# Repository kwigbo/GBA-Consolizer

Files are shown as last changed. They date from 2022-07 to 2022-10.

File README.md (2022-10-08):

  
This work is licensed under a [Creative Commons Attribution-ShareAlike 4.0 International License](http://creativecommons.org/licenses/by-sa/4.0/).

Complete Demo

# Support
[https://www.buymeacoffee.com/kwigbo](https://www.buymeacoffee.com/kwigbo)

# GBA-Consolizer
**GBA Consolizer 3D Printable Case. Build your own Gameboy Advance console! This was designed to have multiple customization points and works with both Gamebox Systems and Woozle consolizer kit. This can also be adapted to any new consolizer kits that may come out in the future. Uses an AGB Gameboy Advance main board.**

# Steps
* **[STEP 1 - Setup](Steps/Step1.md)**
* **[STEP 2 - GBA Prep](Steps/Step2.md)**
* **[STEP 3 - Motherboard Mount](Steps/Step3.md)**
* **[STEP 4 - Consolizer Mount](Steps/Step4.md)**
* **[STEP 5 - Gamebox GBA HD Adapter](Steps/Step5.md)**
* **[STEP 6 - Support Bar](Steps/Step6.md)**
* **[STEP 7 - Frame Assembly (Gamebox)](Steps/Step7.md)**
* **[STEP 7 - Frame Assembly (Woozle)](Steps/Step7b.md)**
* **[STEP 8 - Catridge Tray](Steps/Step8.md)**
* **[STEP 9 - Face Plate](Steps/Step9.md)**
* **[STEP 10 - Rear Plate](Steps/Step10.md)**
* **[STEP 11 - Consolizer Shell](Steps/Step11.md)**
* **[STEP 12 - Lid](Steps/Step12.md)**
* **[STEP 13 - Woozle Gameboy Switch](Steps/Step13.md)**
* **[STEP 14 - Amiibo Holder](Steps/Step14.md)**

Complete Demo
Complete Demo
Complete Demo

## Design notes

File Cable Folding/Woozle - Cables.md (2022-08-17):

# Woozle Cable Folding

**[< -- GBA Prep](../Steps/Step2.md)**

CPU Cable
Display Cable
Complete

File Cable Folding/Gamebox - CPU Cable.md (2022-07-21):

# Gamebox CPU Cable Folding

**[< -- GBA Prep](../Steps/Step2.md)**

Step 1
Step 2
Step 3
Step 4
Complete

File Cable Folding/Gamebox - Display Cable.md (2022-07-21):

# Gamebox Display Cable Folding

**[< -- GBA Prep](../Steps/Step2.md)**

Step 1
Step 2
Step 3
Step 4
Complete

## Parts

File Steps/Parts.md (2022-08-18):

# Parts 

* **Flat Head Machine Screws -> [Amazon](https://a.co/d/2D0doJf)**
* **Brass Embedded Nuts -> [Amazon](https://a.co/d/0SNjTzL)**
* **Rubber Feet -> [Amazon](https://a.co/d/iRyxWAl)**

## Common Parts

* **GBA Frame: 4 - M2x8 Brass Inserts**
* **GBA Front Connection ( Top of GBA ): 2 - M2x10 Screws** 
* **GBA Back Connection: 2 - M2x6 Screws** 
* **Main Shell Connection: 2 - M3x8**
* **4 - 10mmx2mm Rubber Feet**

## GBA Consolizer Mount: 

* **4 - M2x4 Brass Inserts** 
* **2 - M3x8 Brass Inserts**
* **4 - M2x8 Screws**

## Gamebox Parts

* **LED Button ( Gamebox ) -> [Amazon](https://a.co/d/2u8QrSU)**
* **GBHD Screws: 4 - M3x6 Screws**

## Frame Adapter: 

* **4 - M3x8 Brass Inserts**
* **4 - M2x8 Screws**

## Rear Faceplate Connection: 

* **2 - M3x8 Screws** 
* **2 - M2x6 Brass Inserts**
* **2 - M2x8 Screws**

## Woozle Parts

* **Switches -> [Amazon](https://a.co/d/1mCzNco)**
* **LEDs -> [Amazon](https://a.co/d/bPgX2ja)**
* **Switch Board -> [Gerber](../Woozle%20Switch%20Gerber)**

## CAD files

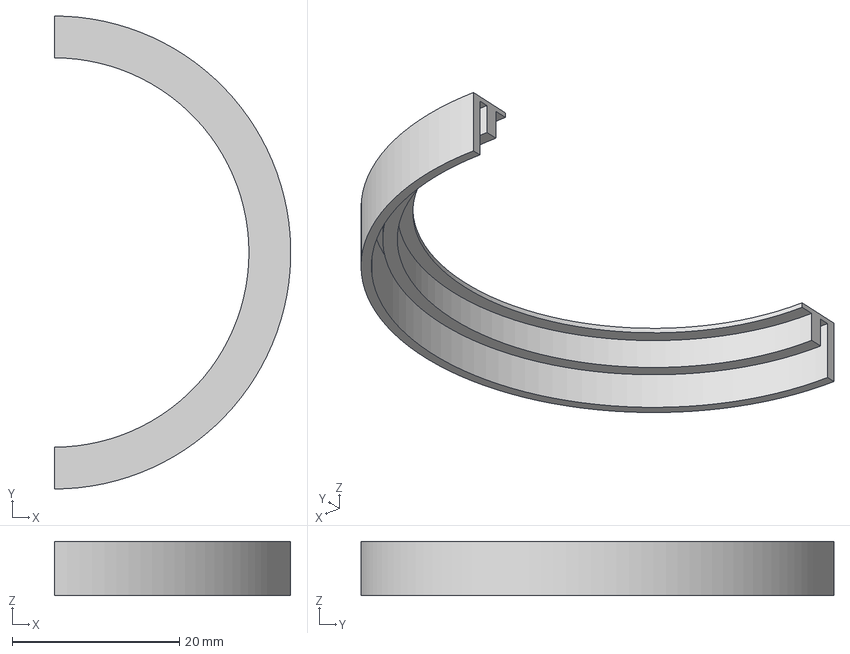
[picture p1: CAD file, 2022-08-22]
Models/Amiibo_Top_Clip_Full.3mf
28.2 x 56.5 x 6.50 mm

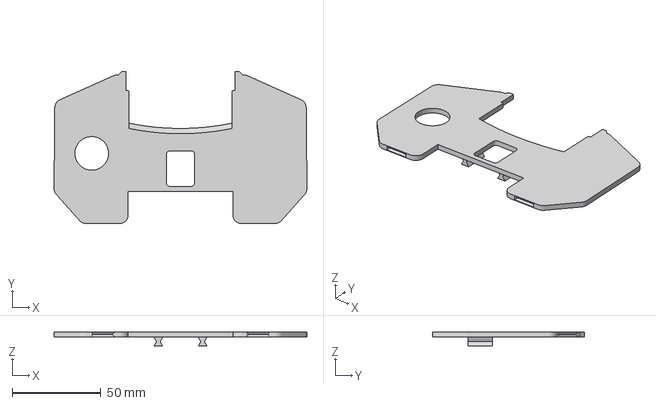
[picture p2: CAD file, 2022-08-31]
Models/Lid_Type_5.3mf
142.8 x 85.9 x 8.00 mm

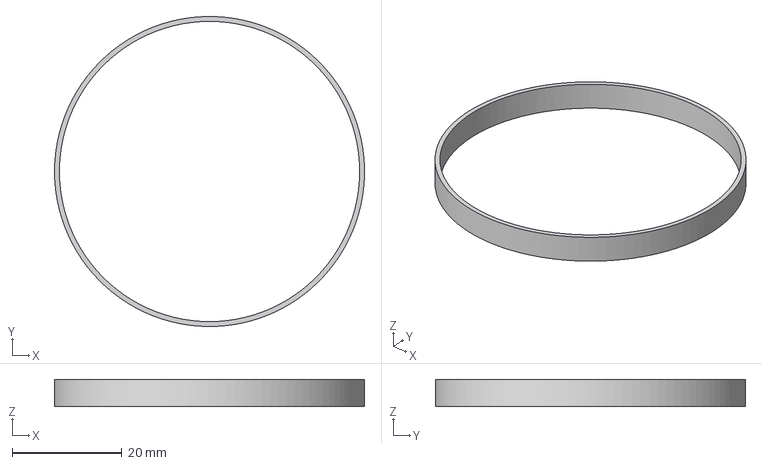
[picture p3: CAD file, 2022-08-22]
Models/Amiibo_Decorative_Ring.3mf
56.5 x 56.5 x 5.00 mm

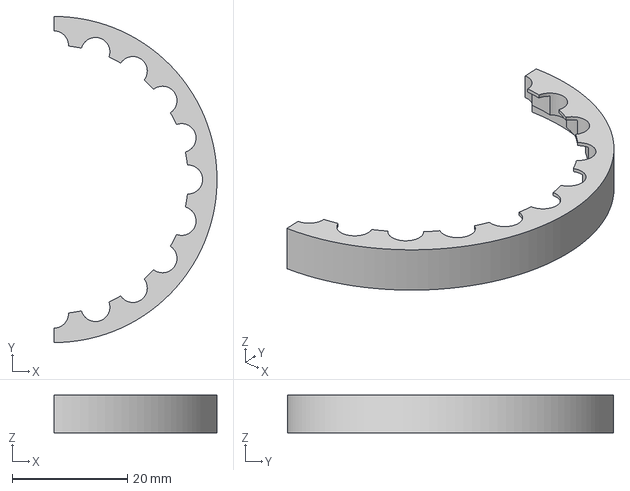
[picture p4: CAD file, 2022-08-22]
Models/Amiibo_Top_Clip_Notched.3mf
28.2 x 56.5 x 6.50 mm

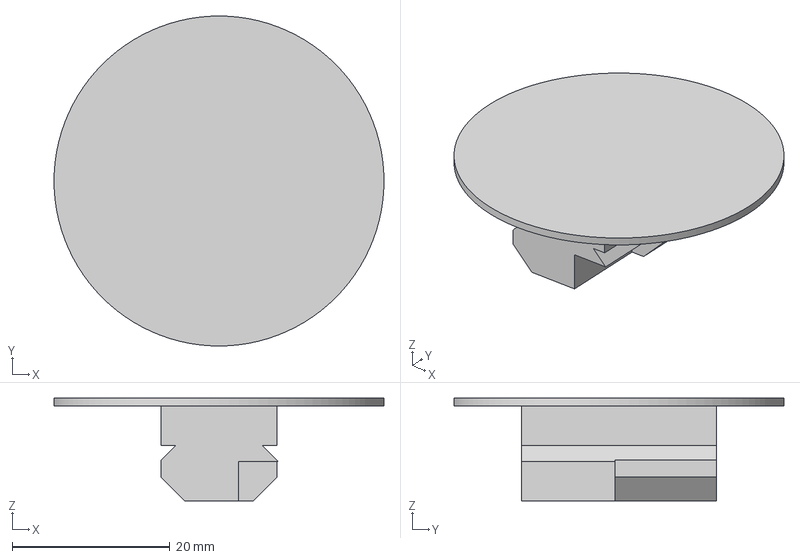
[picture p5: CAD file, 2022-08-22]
Models/Amiibo_Holder_Post_Capacitor_Clearance.3mf
41.8 x 41.8 x 13.0 mm

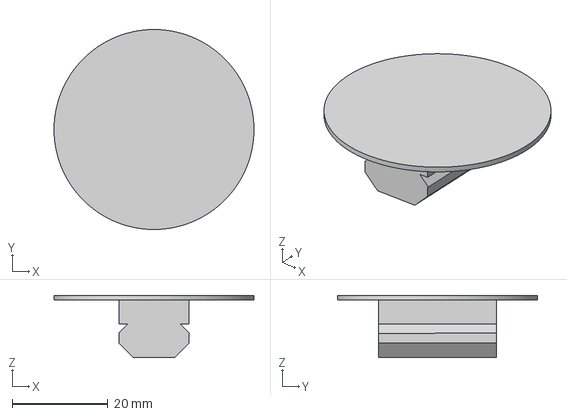
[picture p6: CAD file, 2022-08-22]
Models/Amiibo_Holder_Post.3mf
41.8 x 41.8 x 13.0 mm

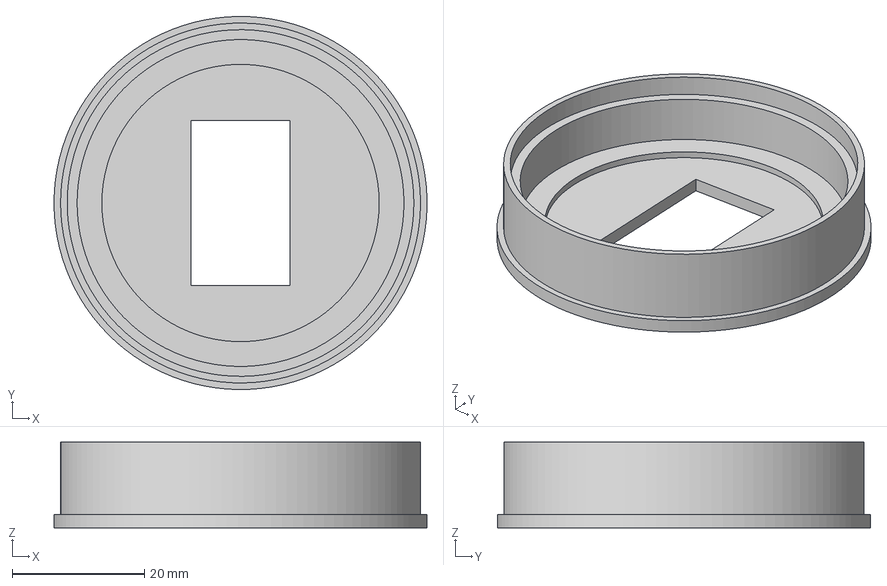
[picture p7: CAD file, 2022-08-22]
Models/Amiibo_Holder_Tray.3mf
56.5 x 56.5 x 13.0 mm

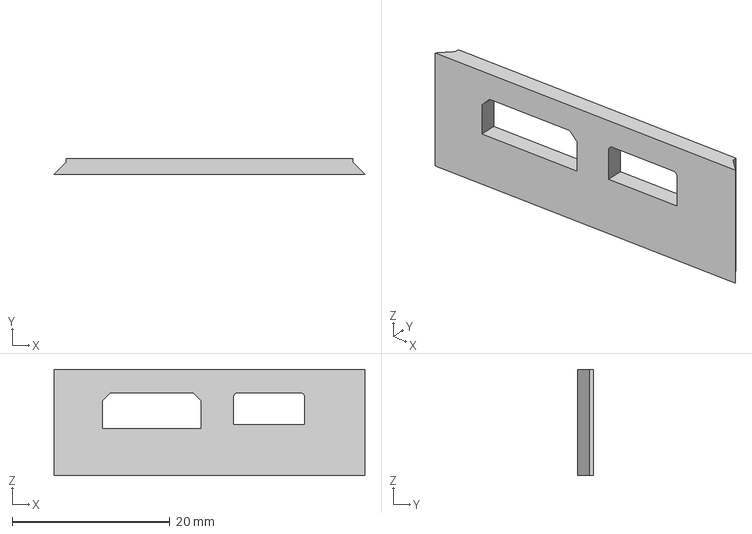
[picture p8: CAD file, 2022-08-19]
Models/Rear_Portplate_Face_Woozle.3mf
39.4 x 2.00 x 13.5 mm

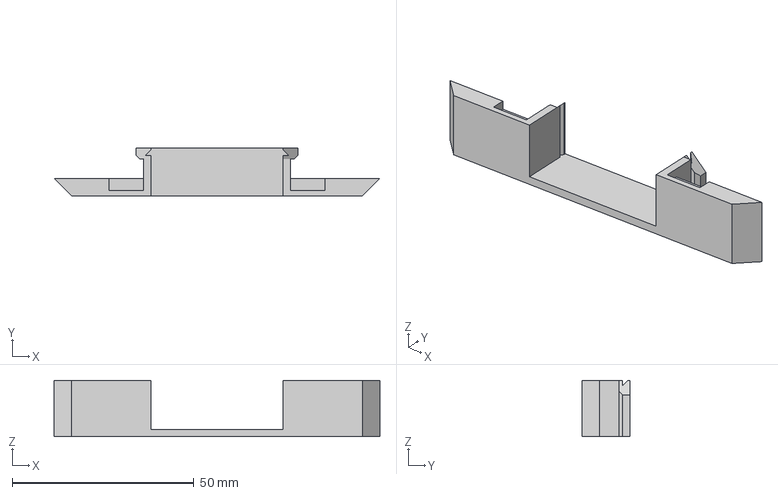
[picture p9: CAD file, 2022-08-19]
Models/Rear_Portplate_Woozle.3mf
89.7 x 13.2 x 15.5 mm

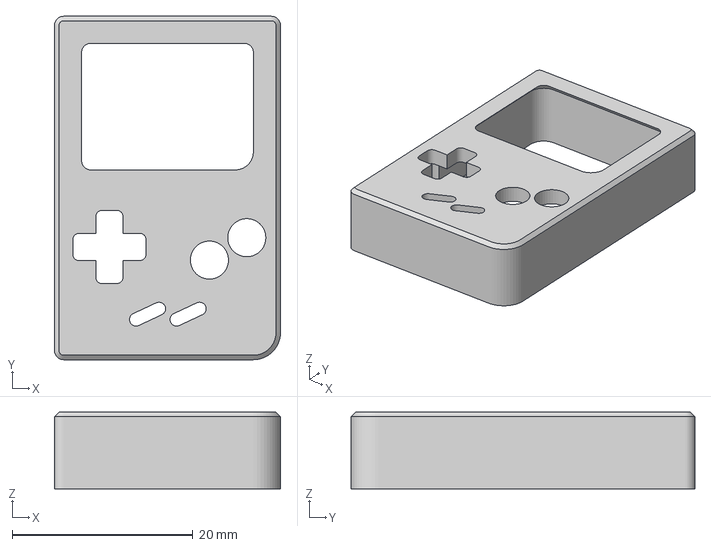
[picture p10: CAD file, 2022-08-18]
Models/Woozle_Gameboy_Switch_Body.3mf
25.0 x 38.0 x 8.50 mm

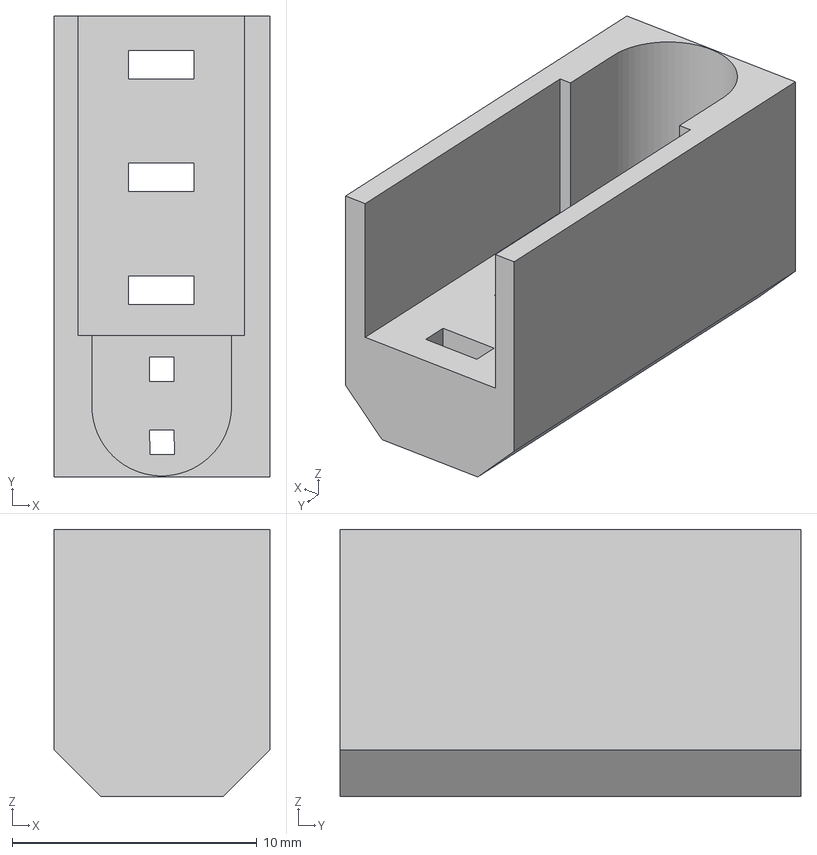
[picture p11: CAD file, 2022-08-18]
Models/Woozle_Switch_Component_Holder.3mf
8.80 x 18.8 x 10.9 mm

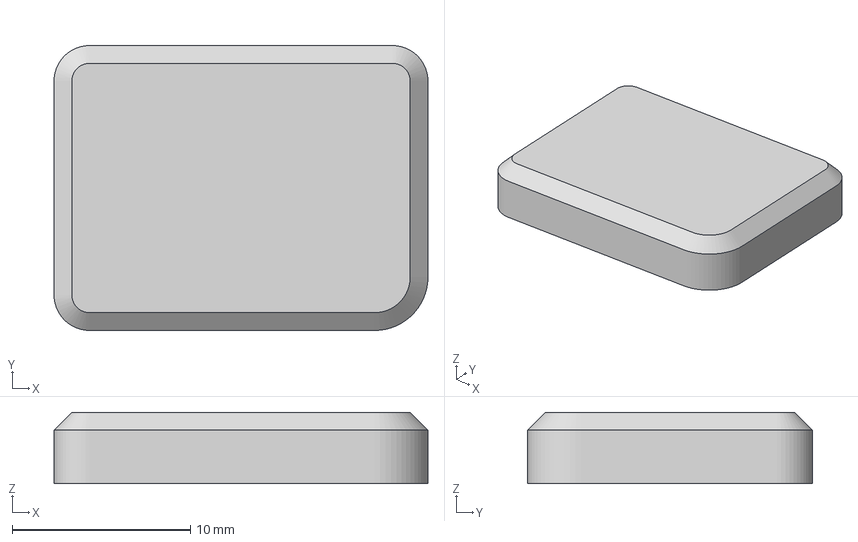
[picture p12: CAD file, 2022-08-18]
Models/Woozle_Gameboy_Switch_Screen.3mf
21.0 x 16.0 x 4.00 mm

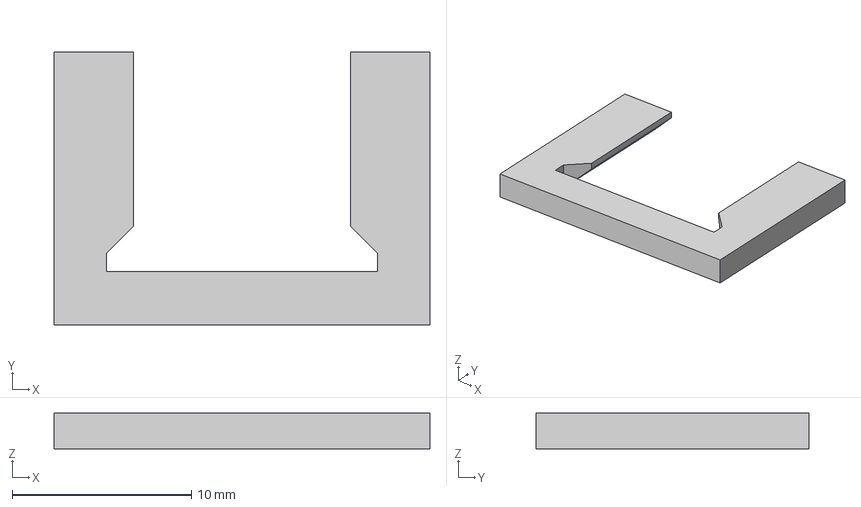
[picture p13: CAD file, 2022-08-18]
Models/Feature_Hold_Down_Pin.3mf
21.0 x 15.3 x 2.00 mm

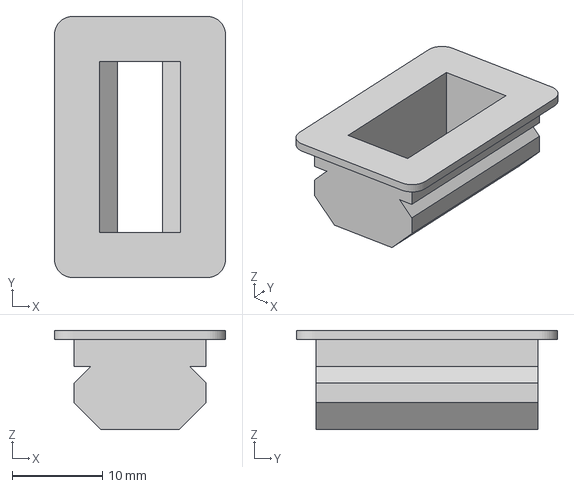
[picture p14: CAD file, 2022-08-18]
Models/Woozle_Switch_Post.3mf
19.0 x 29.0 x 11.0 mm

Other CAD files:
Models/Woozle_Gameboy_Switch_Buttons.3mf
Models/Rear_Plate_Bottom_Woozle.3mf
Models/Face_Plate_Woozle.3mf
Models/Support_Bar_Woozle.3mf
Models/Board_Adapter_Left_Gamebox.3mf
Models/Board_Adapter_Left_Inserts_Gamebox.3mf
Models/Board_Adapter_Right_Gamebox.3mf
Models/Board_Adapter_Right_Inserts_Gamebox.3mf
Models/Calibration_Bottom_Block_Inserts.3mf
Models/Calibration_Bottom_Block_No_Inserts.3mf
Models/Calibration_Top_Block.3mf
Models/Cartridge_Tray_Base_32.3mf
Models/Cartridge_Tray_Base_40.3mf
Models/Cartridge_Tray_Mount_32.3mf
Models/Cartridge_Tray_Mount_40.3mf
Models/Consolizer_Mount_Left.3mf
Models/Consolizer_Mount_Left_Inserts.3mf
Models/Consolizer_Mount_Right.3mf
Models/Consolizer_Mount_Right_Inserts.3mf
Models/Consolizer_Shell.3mf
Models/Eject_Holder.3mf
Models/Eject_Holder_Inserts.3mf
Models/Eject_Holder_Plate.3mf
Models/Eject_Switch.3mf
Models/Face_Plate_Button_Cap_Gamebox.3mf
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

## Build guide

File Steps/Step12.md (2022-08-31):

# STEP 12 - Lid

**[< -- Go Back](../README.md)**

**Print a Lid variation, Eject Switch, Eject Holder Plate and an Eject Holder. The Eject Holder is the only part with an inserts or no inserts version.**

## Parts

* **2 - M2x6 Screws**
* **2 - M2x6 Brass Inserts**

## Files

* **Lids**
	* [Lid Type 1](../Models/Lid_Type_1.3mf)
	* [Lid Type 2](../Models/Lid_Type_2.3mf)
	* [Lid Type 3](../Models/Lid_Type_3.3mf)
	* [Lid Type 4](../Models/Lid_Type_4.3mf)
	* [Lid Type 5](../Models/Lid_Type_5.3mf)
* [Eject Switch](../Models/Eject_Switch.3mf)
* [Eject Holder Plate](../Models/Eject_Holder_Plate.3mf)
* **Eject Holder**
	* [Eject Holder - Inserts](../Models/Eject_Holder_Inserts.3mf)
	* [Eject Holder - No Inserts](../Models/Eject_Holder.3mf)

## Printing Details

* No supports
* 0.2mm layer height

## Lid Types

* **Type 1:** No Holes for embelishment adapters.
* **Type 2:** One embelisment hole ( Left )
* **Type 3:** Two embelisment holes ( Left and Right )
* **Type 4:** One embelisment hole ( Left ) and one circular hole right.
* **Type 5:** One circular hole right.

**Choose a type and print. Type 1 is the minimum needed to cover the top and will be outlined here. All others install the same, they just have options for decorations which will be outlined in the next step.**

## Step 1

**With the Lid upside-down, insert the eject switch as shown below.**

Step 1

## Step 2

**Slide the Eject Holder over the bowtie posts on the Lid. This should slide on loosley and will be secured in a later step.**

Step 2

## Step 3

**Snap the Lid into place. Some pressure is needed and it will click into place.**

Step 3

## Step 4

**Slide the Eject Holder Plate into the slots on the back and secure with two M2x6 Screws.**

Step 4
Step 5

## Complete!!

Step 6

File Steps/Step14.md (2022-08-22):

# STEP 14 - Amiibo Holder

**[< -- Go Back](../README.md)**

**This is not guaranteed to fit all Amiibo. The concept is pretty simple though and Amiibo specific versions are not to difficult to create.**

## Files

* [Amiibo Holder Post - Capacitor](../Models/Amiibo_Holder_Post_Capacitor_Clearance.3mf)
	* This version is for stock capacitor clearance on the left of the console
* [Amiibo Holder Post - Normal](../Models/Amiibo_Holder_Post.3mf)
	* This version does not have the cutout to clear the tall capacitor that is stock on a GBA.
* [Holddown Pin](../Models/Feature_Hold_Down_Pin.3mf)
* [Top Clip Full](../Models/Amiibo_Top_Clip_Full.3mf)
* [Top Clip Notched](../Models/Amiibo_Top_Clip_Notched.3mf)
* [Holder Tray](../Models/Amiibo_Holder_Tray.3mf)
* [Decorative Ring](../Models/Amiibo_Decorative_Ring.3mf)

## Parts Needed
* 1x Holder Post Variant
* 2x Holddown Pins
* 2x Top Clips
* 1x Decorative Ring
* 1x Holder Tray

**Push the Holder Post into the Holder Tray and install in the lid of the consolizer with the two Holddown Pins. Slide the Decorative Ring over the Holder Tray and place an Amiibox in the tray. Use the Holddown Pins to secure the Amiibo in place. The Notched variety helps when there are small pieces of the Amiibo that go beyond the bounds of the tray.**

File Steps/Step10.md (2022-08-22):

# STEP 10 - Rear Plate

**[< -- Go Back](../README.md)**

**Print all pieces flat side down. Note: The Rear Portplate has insets on the back to indicate front and back.**

## Parts

* **2 - M2x8 Screws**

## Files

* **Common Parts**
	* [Rear Plate Top](../Models/Rear_Plate_Top.3mf)
	* [Screw Cover Plate](../Models/Screw_Cover_Plate.3mf)
* **Gamebox Systems**
	* [Rear Portplate](../Models/Rear_Portplate_Gamebox.3mf)
	* [Rear Plate Bottom](../Models/Rear_Plate_Bottom_Gamebox.3mf)
* **Woozle**
	* [Rear Portplate](../Models/Rear_Portplate_Woozle.3mf)
	* [Rear Plate Bottom](../Models/Rear_Plate_Bottom_Woozle.3mf)
	* [Rear Portplate Face](../Models/Rear_Portplate_Face_Woozle.3mf)

## Printing Details

* No supports
* 0.2mm layer height

## Assembly - Step 1

**Slide the Rear Portplate into the Rear Plate Bottom with the indents on the same side as the screw holes of the Rear Plate Bottom (See images below).**

**Note: The Woozle version of the Rear Portplate has an extra piece that has to be slid into place in this step as well. The wide side of the plate goes towards the back of the console.**

Step 1
Step 2

## Assembly - Step 2

**Slide the assembled Rear Plate Bottom onto the Support Bar. Make sure the holes line up. You may have to wiggle the Portplate in order to slide it into position.**

Step 3

## Assembly - Step 3

**Slide the Rear Plate Top into position lined up with the screw holes and attach with the 2 - M2x8 Screws. The screws go through both plates into the Support Bar.**

Step 4

## Assembly - Step 4

**Place the Screw Cover Plate over the screws. This sits in place and will be secured with the lid.**

Step 5

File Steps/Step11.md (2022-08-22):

# STEP 11 - Consolizer Shell

**[< -- Go Back](../README.md)**

**This is a multi-part model but is printed as one piece. The floor is a seperate piece so it can be printed as an infill pattern with zero top layers and zero bottom layers. ( Might be Prusa Slicer only? )**

## Parts

* **2 - M3x8**
* **4 - 10mmx2mm Rubber Feet**

## Files

* [Consolizer Shell](../Models/Consolizer_Shell.3mf)

## Printing Details

* Time: ~5hrs
* No supports
* 0.2mm layer height

**Slide the assembled console frame into the Consolizer Shell. There are alignment posts to help put it in the right position. It should slip right in. Connect the frame to the shell with the two M3x8 SCrews from the bottom ( See images below ). Also, stick the four rubber feet on if desired.**

Step 1
Step 2

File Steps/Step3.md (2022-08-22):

# STEP 3 - Motherboard Mount

**[< -- Go Back](../README.md)**

**Choose a version to print and install the brass inserts/pre-tap the holes.**

## Files

* **Motherboard Mount**
	* [Motherboard Mount Inserts](../Models/Motherboard_Mount_Inserts.3mf)
	* [Motherboard Mount No Inserts](../Models/Motherboard_Mount.3mf)

## Printing Details

**Print the model flat side down. There is a difference as one side has to clear the components on the GBA board.**

* No supports
* 0.2mm layer height

## Brass Inserts

**Four M2x8 brass inserts are need for this part if printing the inserts version.**

**IMPORTANT!: Make sure all matting surfaces (top and bottom) are flush when installing the inserts. Any globs of plastic will affect the final fitment. A razor blade can help especially right after install before the plastic has cooled.Refer the the image below when installing.**

Motherboard Mount

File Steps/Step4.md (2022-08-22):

# STEP 4 - Consolizer Mount

**[< -- Go Back](../README.md)**

**Choose a version to print and install the brass inserts/pre-tap the holes.**

## Files

* **Consolizer Mount**
	* [Consolizer Mount Right Inserts](../Models/Consolizer_Mount_Right_Inserts.3mf)
	* [Consolizer Mount Left Inserts](../Models/Consolizer_Mount_Left_Inserts.3mf)
	* [Consolizer Mount Right No Inserts](../Models/Consolizer_Mount_Right.3mf)
	* [Consolizer Mount Left No Inserts](../Models/Consolizer_Mount_Left.3mf)

## Printing Details

**Print the model flat side down.**

* No supports
* 0.2mm layer height

## Brass Inserts

* **4 - M2x4 Brass Inserts** 
* **2 - M3x8 Brass Inserts**

**IMPORTANT!: Make sure all matting surfaces (top and bottom) are flush when installing the inserts. Any globs of plastic will affect the final fitment. A razor blade can help especially right after install before the plastic has cooled. Refer the the image below when installing. Two post will remain empty and are a passthrough hole for screws in another step.**

Consolizer Mount

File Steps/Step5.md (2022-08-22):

# STEP 5 - Gamebox GBA HD Adapter

**[< -- Go Back](../README.md)**

**Choose a version to print and install the brass inserts/pre-tap the holes.**

## Files

* **Consolizer Mount**
	* [Board Adapter Right Inserts](../Models/Board_Adapter_Right_Inserts_Gamebox.3mf)
	* [Board Adapter Left Inserts](../Models/Board_Adapter_Left_Inserts_Gamebox.3mf)
	* [Board Adapter Right No Inserts](../Models/Board_Adapter_Right_Gamebox.3mf)
	* [Board Adapter Left No Inserts](../Models/Board_Adapter_Left_Gamebox.3mf)

## Printing Details

**Print the model flat side down.**

* No supports
* 0.2mm layer height

## Brass Inserts

* **4 - M3x8 Brass Inserts**

**IMPORTANT!: Make sure all matting surfaces (top and bottom) are flush when installing the inserts. Any globs of plastic will affect the final fitment. A razor blade can help especially right after install before the plastic has cooled. Refer the the image below when installing.**

Board Adapter

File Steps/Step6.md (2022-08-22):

# STEP 6 - Support Bar

**[< -- Go Back](../README.md)**

**Choose a version to print and install the brass inserts/pre-tap the holes.**

## Files

* **Support Bar (Gamebox)**
	* [Support Bar Inserts](../Models/Support_Bar_Inserts_Gamebox.3mf)
	* [Support Bar No Inserts](../Models/Support_Bar_Gamebox.3mf)

* **Support Bar (Woozle)**
	* [Support Bar Inserts](../Models/Support_Bar_Inserts_Woozle.3mf)
	* [Support Bar No Inserts](../Models/Support_Bar_Woozle.3mf)

## Printing Details

**Print the model flat side down.**

* No supports
* 0.2mm layer height

## Brass Inserts

* **2 - M2x6 Brass Inserts - Gamebox**
* **2 - M2x4 Brass Inserts - Woozle**

**Inserts for the woozle bar are slightly shorter.**

**IMPORTANT!: Make sure all matting surfaces (top and bottom) are flush when installing the inserts. Any globs of plastic will affect the final fitment. A razor blade can help especially right after install before the plastic has cooled.Refer the the image below when installing.**

Support Bar

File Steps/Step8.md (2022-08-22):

# STEP 8 - Cartride Tray

**[< -- Go Back](../README.md)**

**Print the Cartridge Tray Base face down. The tray works for both 32 and 40 pin models. Print the Cartridge Tray Mount flat side down. There are two variation of this based on 32 or 40 pin GBA. A slight dab of super glue attaches the Cartridge Tray Base to the Cartridge Tray Mount**

**Place the Cartrige Tray Assembly in position as shown below. Be carful of the components on the board. It should slip into place under the cartridge port.**

**No Screws needed yet as the screws from the faceplate will pass through this part to hold it in place.**

## Files

* **32 Pin**
	* [Cartridge Tray Base ( 32 pin )](../Models/Cartridge_Tray_Base_32.3mf)
	* [Cartridge Tray Mount ( 32 pin )](../Models/Cartridge_Tray_Mount_32.3mf)
* **40 Pin**
	* [Cartridge Tray Base ( 40 pin )](../Models/Cartridge_Tray_Base_40.3mf)
	* [Cartridge Tray Mount ( 40 pin )](../Models/Cartridge_Tray_Mount_40.3mf)

## Printing Details

* No supports
* 0.2mm layer height

Cartridge Tray

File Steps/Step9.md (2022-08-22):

# STEP 9 - Face Plate

**[< -- Go Back](../README.md)**

**Print the Face Plate face down. Print the button with the narrow side down.**

**Place the button in the Face Plate and gently rest the tabs over the Catridge Tray Holes. Flip it over and gently pull the bottom of the Face Plate over the SNES port. It should fit right in with possibly a slight click into place (See Image Face Plate A and B).**

**Check that the button clicks easy and does not stick. Check that the Face Plate sits flush against the SNES port.**

**Use two M2x10 screws through both the Face Plate and the Cartridge Tray to secure both (See Image Face Plate C).**

## Parts

* 2 - M2x10 Screws

## Files

* **Gamebox Systems**
	* [Faceplate](../Models/Face_Plate_Gamebox.3mf)
	* [Button](../Models/Face_Plate_Button_Cap_Gamebox.3mf)
* **Woozle**
	* [Faceplate](../Models/Face_Plate_Woozle.3mf)

## Printing Details

* No supports
* 0.2mm layer height

Face Plate A
Face Plate B
Face Plate C

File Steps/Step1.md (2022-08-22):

# STEP 1 - Setup

**[< -- Go Back](../README.md)**

**Print the test pieces and gather parts.**

[Parts List](Parts.md)

## Files

* [Top Block](../Models/Calibration_Top_Block.3mf)
* **Print the bottom based on whether you will use inserts or not.**
	* [Bottom Block Inserts](../Models/Calibration_Bottom_Block_Inserts.3mf)
	* [Bottom Block No Inserts](../Models/Calibration_Bottom_Block_No_Inserts.3mf)

## Printing Details

* No supports
* 0.2mm layer height

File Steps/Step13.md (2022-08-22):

# STEP 13 - Woozle Gameboy Switch

**[< -- Go Back](../README.md)**

**You will need one switch and one LED along with the PCB and printed parts to complete the switch.**

* **Switch Board -> [Gerber](../Woozle%20Switch%20Gerber)**
* **Switches -> [Amazon](https://a.co/d/1mCzNco)**
* **LEDs -> [Amazon](https://a.co/d/bPgX2ja)**

## Files

* **Component Post**
	* [Component Holder](../Models/Woozle_Switch_Component_Holder.3mf)
	* [Switch Post](../Models/Woozle_Switch_Post.3mf)
	* [Holddown Pin x 2](../Models/Feature_Hold_Down_Pin.3mf)
* **Gameboy Parts**
	* [Gameboy Body](../Models/Woozle_Gameboy_Switch_Body.3mf)
	* [Gameboy Screen](../Models/Woozle_Gameboy_Switch_Screen.3mf)
	* [Gameboy Buttons](../Models/Woozle_Gameboy_Switch_Buttons.3mf)

## Printing Details

**Print the Component Holder flat side down. Print the Switch Post with the flange on the print bed. All other parts printed flat side down.**

* No supports
* 0.2mm layer height

## Assembly

* **Slide the Component Holder into the Switch Post and then insert the switch and LED. The flat side of the LED goes towards the switch.**
* **Install the proper resistor on the board based on your choice of LED. The resistor should be on the side with the print.**
* **Place the PCB over the LED and Switch pins with the silkscreen text visible from the bottom.**
* **Solder the pins of the switch and LED to the PCB. This will hold all the components in place.**
* **Place the switch assembly through the lid and secure with the two Holddown Pins**
* **(Optional) Connect wires to a JST connector to make the lid detachable.**
* **Wire the switch to the Consolizer board as pictured below.**

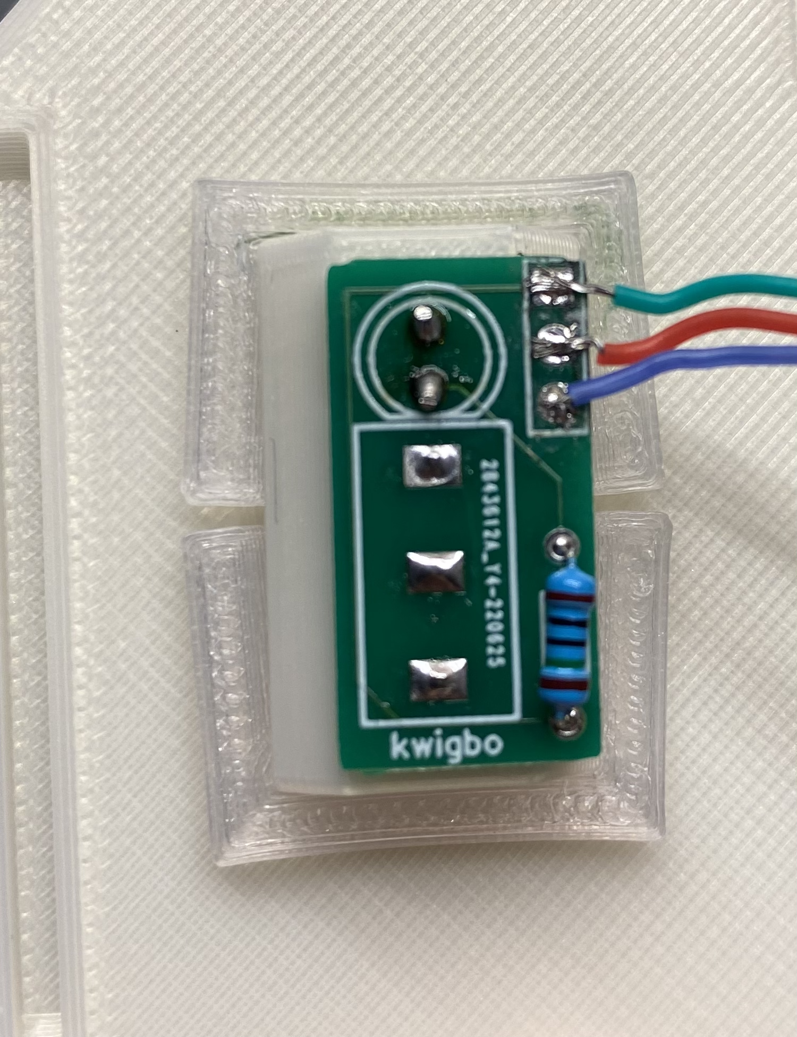
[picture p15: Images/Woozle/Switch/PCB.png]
PCB

Connections

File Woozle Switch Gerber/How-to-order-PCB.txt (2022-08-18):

How to Order PCB

Please refer to:
https://docs.easyeda.com/en/PCB/Order-PCB

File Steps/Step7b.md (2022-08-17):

# STEP 7 - Frame Assembly (Woozle)

**[< -- Go Back](../README.md)**

## Step 1 - Consolizer Mounts

**Attach the Consolizer Mounts to the Motherboard Mount. The flat sides should go together. There are four screws that pass through the Consolizer Mounts into the four points on the Motherboard Mount. See image below for details.**

## Parts

* **4 - M2x8 Screws**

Step 1

## Step 2 - Support Bar

**Install the support bar on the Consolizer Mounts.**

## Parts

* **2 - M2x8 Screws** 

Step 2a
Step 2b

## Step 3 - GBA Motherboard

**Gently place the GBA motherboard on the Motherboard Mount and attach with the two screws to the back of the console. The front two screw will remain empty for now as they are used for the faceplate attachment. See Step 3a image below.**

**Note: The display ribbon should go between the GBA Motherboard and the Motherboard Mount in the small space created. The cables should feed down through the Consolizer Mounts on each side. See Step 3b image below.**

## Parts

* **2 - M2x6 Screws** 

Step 3a
Step 3b

## Step 4 - Woozle Board

**Attach the Woozle board the Consolizer Mounts with the components facing up. The M2x4 screws should be used towards the back of the console near the ports. The longer screws go towards the front where the SNES port is located.**

## Parts

* **2 - M2x4 Screws**
* **2 - M2x6 Screws**

Step 4

## Step 5 - Test

**The console should now be functional and it's a good idea to test it at this point before continuing. You can always temporaily attach the front of the GBA board with 2 - M2x6 Screws just to hold it securly during testing.**

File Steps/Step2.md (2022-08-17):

# STEP 2 - GBA Prep

**[< -- Go Back](../README.md)**

**The link port needs to be removed from the GBA motherboard for this design. Future plans are to relocate the port to the rear of the console.**

## Gambox Systems

* [Macho Nacho Install YouTube](https://www.youtube.com/watch?v=TSE6hmjlmOE)
* **[Display Cable Folding](../Cable%20Folding/Gamebox%20-%20Display%20Cable.md)**
* **[CPU Cable Folding](../Cable%20Folding/Gamebox%20-%20CPU%20Cable.md)**

## Woozle

* [Macho Nacho Install YouTube](https://www.youtube.com/watch?v=oOdEZN_bgfA)
* **[Cable Folding](../Cable%20Folding/Woozle%20-%20Cables.md)**

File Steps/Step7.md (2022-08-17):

# STEP 7 - Frame Assembly (Gamebox)

**[< -- Go Back](../README.md)**

## Step 1 - Consolizer Mounts

**Attach the Consolizer Mounts to the Motherboard Mount. The flat sides should go together. There are four screws that pass through the Consolizer Mounts into the four points on the Motherboard Mount. See image below for details.**

## Parts

* **4 - M2x8 Screws**

Step 1

## Step 2 - Board Adpaters

**Attach the Board Adapters to the Consolizer Mounts. The flat sides go together. See image below for proper orientation. The front Consolizer Mount screws should get covered in this step.**

## Parts

* **4 - M2x8 Screws**

Step 2

## Step 3 - GBHD Board

**Attach the GBHD board to the Board Adapters with the components facing up towards the Motherboard Mount. The ports should face the rear, which is the wider side of the Motherboard Mount.**

## Parts

* **4 - M3x6 Screws**

Step 3

## Step 4 - Support Bar

**Attach the display ribbon cable to the front of the GBA motherboard (Image 4a). Make sure the ribbon is seated fully (Image not seated to show orientation of the cable). Rest the GBA motherboard on the frame as pictured below (Image 4b) and feed the CPU ribbon into the frame. Install the Support Bar. See Image 4B for support bar orientation.**

## Parts

* **2 - M3x8 Screws** 

Step 4a
Step 4b

## Step 5 - GBA Motherboard

**Gently place the GBA motherboard on the Motherboard Mount and attach with the two screws to the back of the console. The front two screw will remain empty for now as they are used for the faceplate attachment.**

**Note: The display ribbon should go between the GBA Motherboard and the Motherboard Mount in the small space created. See Step 5b image below.**

## Parts

* **2 - M2x6 Screws** 

Step 5a
Step 5b

## Step 6 - Display Cable

**Gently tuck the display ribbon cable under the GBA motherboard. Hold it at the font where it attaches to stop it from pushing out the front.**

Step 6

## Step 7 - CPU Cable

**One of the trickies parts is to attach the CPU ribbon cable to the GBAHD board. If bent correctly you should be able to wiggle it into place.**

**Note: I will probably get some more of these and figure out alternate folds that works better. I only had one and didn't want to bend it too much. You may have to unmount the GBAHD board from the bottom to plug it in.**

Step 7

## Step 8 - Test

**The console should now be functional and it's a good idea to test it at this point before continuing. You can always temporaily attach the front of the GBA board with 2 - M2x6 Screws just to hold it securly during testing.**

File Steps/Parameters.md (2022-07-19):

# Parameters

* **M2ScrewHole** - Hole where the M2 screw thread in. ( Screw or Brass Insert )
	* 1.80mm - Screw Hole
	* 3.1mm - Brass Insert
* **M2ScrewPassThrough** - Hole used to let an M2 pass through and catch on the head.
	* 2.5mm
* **M3ScrewHole** - Hole where the M3 screw thread in. ( Screw or Brass Insert )
	* 2.75mm - Screw Hole
	* 4.5mm - Brass Insert
* **M3ScrewPassThrough** - Hole used to let an M# pass through and catch on the head.
	* 3.15mm
* **M3HeadDiameter** - Diameter to allow an M3 head to pass through
	* 5.15mm

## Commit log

2022-07-20 Initial documentation for cable folding
2022-07-20 Updated CPU cable folding page
2022-07-21 Added images of the frame pieces
2022-07-21 Folder renaming
    [Board Adapter Left.3mf, Board Adapter Right.3mf, Consolizer Mount Left.3mf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]
2022-07-21 Added image files for frame assembly
2022-07-21 Added details for step 8
    [Cartridge Tray Mount_32 pin.3mf, Cartridge Tray Mount_40 pin.3mf]
2022-07-21 Paths updated
    [Cartridge Tray Mount_32.3mf, Cartridge Tray Mount_40.3mf]
2022-07-21 Details for step 9
    [Face Plate Button Cap.3mf, Face Plate.3mf]
2022-07-22 Added files for final steps. Completed details for Step 10
    [Rear Bottom Plate.3mf, Rear Faceplate.3mf, Rear Plate Top.3mf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]
2022-07-22 Rename files
    [Rear Plate Bottom.3mf, Rear Portplate.3mf]
2022-07-22 Added details to step 12
    [Lid Type 1.3mf, Lid Type 2.3mf, Lid Type 3.3mf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]
2022-07-23 Updated models for the cartridge tray
    [Cartridge Tray Base.3mf, Cartridge Tray Base_32.3mf, Cartridge Tray Base_40.3mf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]
2022-07-23 Updated lid and shell to pull the sides in
    [Consolizer Shell.3mf, Lid Type 1.3mf, Lid Type 2.3mf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]
2022-07-23 Fixed issues with screw holes in main shell
    [Consolizer Shell.3mf]
2022-07-25 Fixed the 40 pin cartridge tray layout
    Added insets for screw on rear top plate
    [Cartridge Tray Base_40.3mf, Cartridge Tray Mount_40.3mf, Rear Plate Top.3mf]
2022-07-25 Added notches to lids to help keep the sides pulled in.
    [Lid Type 1.3mf, Lid Type 2.3mf, Lid Type 3.3mf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]
2022-07-25 Increased hole size on eject holder plate to avoid lift in the lid
    [Eject Holder Plate.3mf]
2022-07-26 Fixed hole alignment on eject holder plate.
    [Eject Holder Plate.3mf]
2022-08-08 Updated clearance on lid connection
    [Lid Type 1.3mf, Lid Type 2.3mf, Lid Type 3.3mf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]
2022-08-17 Added support bar for woozle varient
    [Support Bar (Woozle).3mf]
2022-08-17 Added details for Woozle consolizer specifics for frame assmbly and cable folding
2022-08-17 Updated brass insert sizes for woozle support bar
2022-08-18 Added Woozle specific faceplate
    [Face Plate.3mf]
2022-08-18 Added Woozle rear plate specific parts
    [Rear Plate Bottom.3mf, Rear Plate Top.3mf, Rear Portplate.3mf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]
2022-08-18 Added Gerber files for Woozle switch PCB
    [Drill_PTH_Through.DRL, Gerber_BoardOutlineLayer.GKO, Gerber_BottomLayer.GBL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]
2022-08-18 Added details on assembly and installation of the switch for the woozle varient
    [Gameboy Switch Body.3mf, Gameboy Switch Buttons.3mf, Gameboy Switch Screen.3mf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]
2022-08-18 Updated image of PCB
2022-08-19 Added woozle rear plate updated models.
    [Rear Portplate Face.3mf, Rear Portplate.3mf]
2022-08-19 Updated description on rear portplate assembly.
2022-08-22 File reorganization
    [Board_Adapter_Left_Gamebox.3mf, Board_Adapter_Left_Inserts_Gamebox.3mf, Board_Adapter_Right_Gamebox.3mf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]
2022-08-22 Moved all models to one folder for easier upload to 3dprint sites.
    [Board_Adapter_Left_Gamebox.3mf, Board_Adapter_Left_Inserts_Gamebox.3mf, Board_Adapter_Right_Gamebox.3mf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]
2022-08-22 Added details and files for the Amiibo holder
    [Amiibo_Decorative_Ring.3mf, Amiibo_Holder_Post.3mf, Amiibo_Holder_Post_Capacitor_Clearance.3mf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]
2022-08-31 Added type 5 lid
    [Lid_Type_5.3mf]

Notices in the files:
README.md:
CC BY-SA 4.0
